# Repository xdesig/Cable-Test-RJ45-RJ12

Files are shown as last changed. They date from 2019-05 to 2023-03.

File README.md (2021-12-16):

# Cable Test V0.4

You want a PCB to exercise or learn to solder THT components, here you have one of many.
This provides you with a device to test network cables (RJ45) and telephone cables (RJ12 / 11),
made with normal components, (the most complicated being the LED bar).
You can be complemented with more diodes 1N4148 in anti-parallel soldiers under the LEDS (2, 5..9) to allow to check all cable faults.

Buy PCB in [PCBWAY]

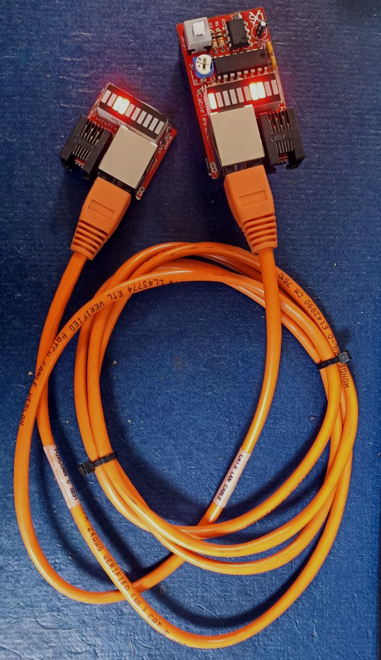
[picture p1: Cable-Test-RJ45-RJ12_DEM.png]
Top view

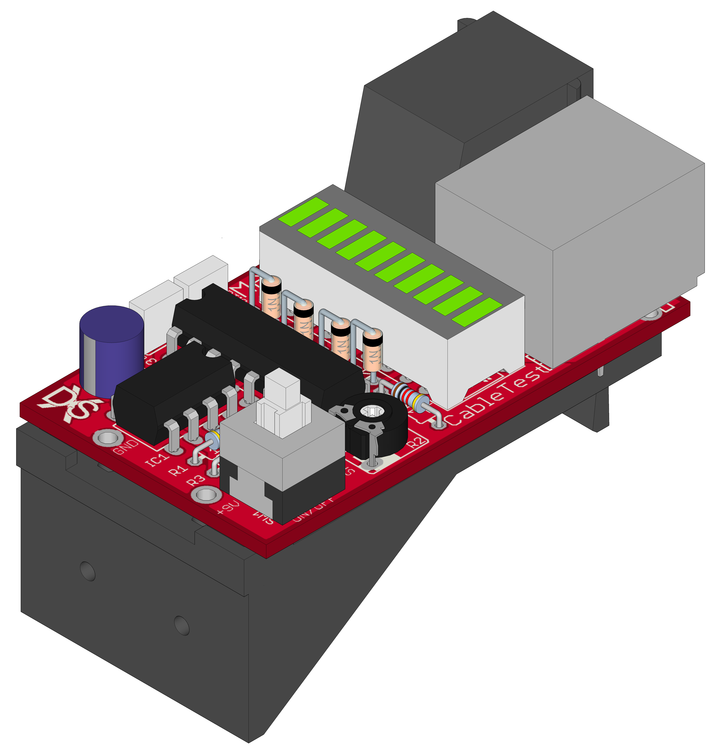
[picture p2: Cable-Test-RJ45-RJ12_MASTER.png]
Render

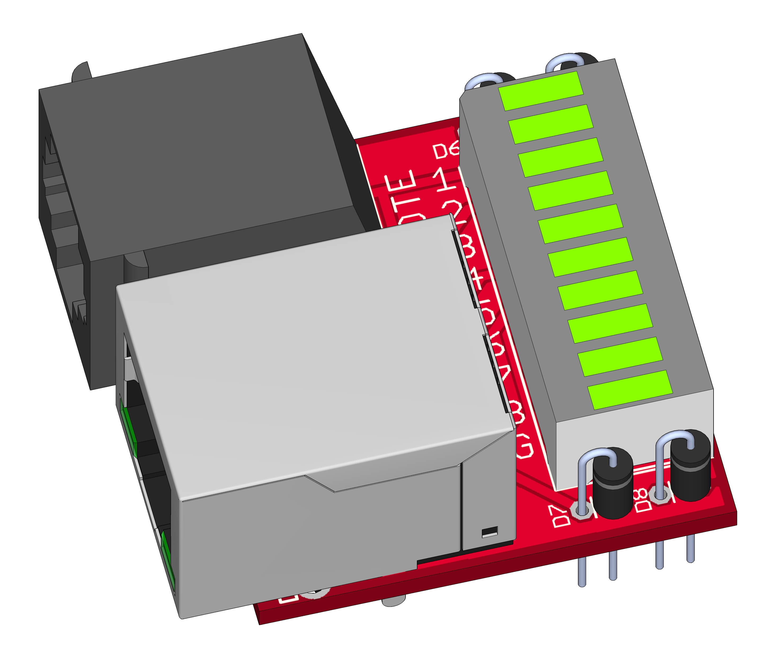
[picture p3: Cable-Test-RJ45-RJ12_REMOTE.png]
Botom view


#B.O.M.
<table cellspacing="0" border="0">
	<colgroup width="38"></colgroup>
	<colgroup width="70"></colgroup>
	<colgroup span="2" width="133"></colgroup>
	<colgroup width="122"></colgroup>
	<colgroup width="85"></colgroup>
	<tr>
		<td height="17" align="left">Qty </td>
		<td align="left">Value</td>
		<td align="left">Device</td>
		<td align="left">Package</td>
		<td align="left">Parts</td>
		<td align="left">Description</td>
	</tr>
	<tr>
		<td height="17" align="left"><br></td>
		<td align="left"><br></td>
		<td align="left"><br></td>
		<td align="left"><br></td>
		<td align="left"><br></td>
		<td align="left"><br></td>
	</tr>
	<tr>
		<td height="17" align="right" sdval="2" sdnum="1110;">2</td>
		<td align="left"><br></td>
		<td align="left"> DS1128-S80BP</td>
		<td align="left">DS1128-S80BP</td>
		<td align="left">J1, J3</td>
		<td align="left">Ethernet Connector</td>
	</tr>
	<tr>
		<td height="17" align="right" sdval="1" sdnum="1110;">1</td>
		<td align="left"><br></td>
		<td align="left"> BATTERY9V</td>
		<td align="left">BATTCON_9V</td>
		<td align="left">BAT1</td>
		<td align="left">Battery Holders</td>
	</tr>
	<tr>
		<td height="17" align="right" sdval="1" sdnum="1110;">2</td>
		<td align="left">100nF</td>
		<td align="left"> C2.5/2</td>
		<td align="left">C2.5-2</td>
		<td align="left">C2, C3</td>
		<td align="left">CAPACITOR</td>
	</tr>
	<tr>
		<td height="17" align="right" sdval="2" sdnum="1110;">2</td>
		<td align="left">10K</td>
		<td align="left"> 1/4 Watt</td>
		<td align="left">0204/7</td>
		<td align="left">R1, R3</td>
		<td align="left">RESISTOR</td>
	</tr>
	<tr>
		<td height="17" align="right" sdval="1" sdnum="1110;">1</td>
		<td align="left">10uF/16V</td>
		<td align="left">2.5mm&ndash;6mm</td>
		<td align="left">E2,5-6</td>
		<td align="left">C1</td>
		<td align="left">POLARIZED CAPACITOR</td>
	</tr>
	<tr>
		<td height="17" align="right" sdval="1" sdnum="1110;">1</td>
		<td align="left">1K</td>
		<td align="left"> R-EU_0204/7</td>
		<td align="left">0204/7</td>
		<td align="left">R4</td>
		<td align="left">RESISTOR</td>
	</tr>
	<tr>
		<td height="17" align="right" sdval="1" sdnum="1110;">8</td>
		<td align="left">1N4148</td>
		<td align="left"> DIODE-D-2.5</td>
		<td align="left">D-2.5</td>
		<td align="left">D1...D8</td>
		<td align="left">DIODE</td>
	</tr>
	<tr>
		<td height="17" align="right" sdval="1" sdnum="1110;">1</td>
		<td align="left">4017N</td>
		<td align="left"> 4017N</td>
		<td align="left">DIL16</td>
		<td align="left">IC2</td>
		<td align="left">COUNTER/DIVIDER</td>
	</tr>
	<tr>
		<td height="17" align="right" sdval="1" sdnum="1110;">1</td>
		<td align="left">47K</td>
		<td align="left"> TRIM_EU-CA6V</td>
		<td align="left">CA6V</td>
		<td align="left">R2</td>
		<td align="left">POTENTIOMETER</td>
	</tr>
	<tr>
		<td height="17" align="right" sdval="1" sdnum="1110;">1</td>
		<td align="left">NE555</td>
		<td align="left"> ICM555</td>
		<td align="left">DIL08</td>
		<td align="left">IC1</td>
		<td align="left">TIMER</td>
	</tr>
	<tr>
		<td height="17" align="right" sdval="1" sdnum="1110;">2</td>
		<td align="left">LB10</td>
		<td align="left"> LB10</td>
		<td align="left">LB10</td>
		<td align="left">LB1,LB2</td>
		<td align="left">10 LED BLOCK</td>
	</tr>
	<tr>
		<td height="17" align="right" sdval="1" sdnum="1110;">1</td>
		<td align="left">SW</td>
		<td align="left"> PB7-0</td>
		<td align="left">PB07_0</td>
		<td align="left">SW1</td>
		<td align="left">8x8mm   DPDT Self-locking Switch</td>
	</tr>
	<tr>
		<td height="17" align="right" sdval="2" sdnum="1110;">2</td>
		<td align="left">RJ11</td>
		<td align="left"> RJ11-6PTH</td>
		<td align="left">95001-6P6C</td>
		<td align="left">J2, J4</td>
		<td align="left">RJ12 Socket 95001-6P6C Female</td>
	</tr>
</table>

## Author and license
* Author: [XDeSIG][TWI01]
* License: CERN-OHL-W V2 [CERN-OHL] and Attribution-ShareAlike 4.0 International [CCBY-SA4.0]

<!-- links -->

[CERN-OHL]: https://ohwr.org/cernohl
[CCBY-SA4.0]: http://creativecommons.org/licenses/by-sa/4.0/
[TWI01]: https://twitter.com/xdesig
[DEM]: Cable-Test-RJ45-RJ12_DEM.png
[PHT]: Cable-Test-RJ45-RJ12_MASTER.png
[RENDER]: Cable-Test-RJ45-RJ12_REMOTE.png

[PCBWAY]: https://www.pcbway.com/project/shareproject/Cable_Test_RJ45___RJ12.html

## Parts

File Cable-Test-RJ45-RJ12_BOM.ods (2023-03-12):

Qty | Value | Device | Package | Parts | Description | LCSC link (https://www.lcsc.com/)
2 |  | DS1128-S80BP | DS1128-S80BP | J1, J3 | Ethernet Connector | C86586 (https://www.lcsc.com/product-detail/Ethernet-Connectors-Modular-Connectors-RJ45-RJ11_CONNFLY-Elec-DS1128-S80BP_C86586.html)
1 |  | BATTERY9V | BATTCON_9V | BAT1 | Battery Holders |  | Aliexpress (https://es.aliexpress.com/item/32945156022.html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)
2 | 100nF | C2.5/2 | C2.5-2 | C2,C3 | CAPACITOR | C353904 (https://www.lcsc.com/product-detail/Ceramic-Disc-Capacitors_Dersonic-CC1H104ZC1PD3F5P3003_C353904.html)
2 | 10K | 1/4 Watt | 0204/7 | R1, R3 | RESISTOR | C61299 (https://www.lcsc.com/product-detail/Through-Hole-Resistors_UNI-ROYAL-Uniroyal-Elec-CFR0W4J0103A50_C61299.html)
1 | 10uF/16V | 2.5mm – 6mm | E2,5-6 | C1 | POLARIZED CAPACITOR | C1664919 (https://www.lcsc.com/product-detail/Aluminum-Electrolytic-Capacitors-Leaded_Rubycon-16TWL10KEFC6-3X11_C1664919.html)
1 | 1K | R-EU_0204/7 | 0204/7 | R4 | RESISTOR | C176465 (https://www.lcsc.com/product-detail/Through-Hole-Resistors_YAGEO-MFR-25JT-52-1K_C176465.html)
8 | 1N4148 | DIODE-D-2.5 | D-2.5 | D1 ... D8 | DIODE | C14538 (https://www.lcsc.com/product-detail/Switching-Diode_ST-Semtech-1N4148_C14538.html)
1 | HC4017N | HC4017N | DIL16 | IC2 | COUNTER/DIVIDER | C1548031 (https://www.lcsc.com/product-detail/Counters-Dividers_Texas-Instruments-CD74HC4017EG4_C1548031.html)
1 | 47K | TRIM_EU-CA6V | CA6V | R2 | POTENTIOMETER | C840703 (https://www.lcsc.com/product-detail/Variable-Resistors-Potentiometers_BOURNS-3306F-1-103_C840703.html)
1 | NE555 | ICM555 | DIL08 | IC1 | TIMER | C5157852 (https://www.lcsc.com/product-detail/Timers-Clock-Oscillators_Gcore-NE555_C5157852.html)
2 | LB10 | LB10 | LB10 | LB1, LB2 | 10 LED BLOCK |  | Aliexpress (https://es.aliexpress.com/item/32346585157.html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)
1 | SW | PB7-0 | PB07_0 | SW1 | 8x8mm DPDT Self-locking Switch | C194403 (https://www.lcsc.com/product-detail/Push-span-style-background-color-ff0-Switches-span_GANGYUAN-PB21E09471-32_C194403.html)
2 | RJ12 | RJ12-6PTH | 95001-6P6C | J2, J4 | RJ12 Socket 95001-6P6C Female | C2902699 (https://www.lcsc.com/product-detail/Ethernet-Connectors-Modular-Connectors-RJ45-span-style-background-color-ff0-RJ11-span_Ckmtw-Shenzhen-Cankemeng-R-RJ11R06P-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)

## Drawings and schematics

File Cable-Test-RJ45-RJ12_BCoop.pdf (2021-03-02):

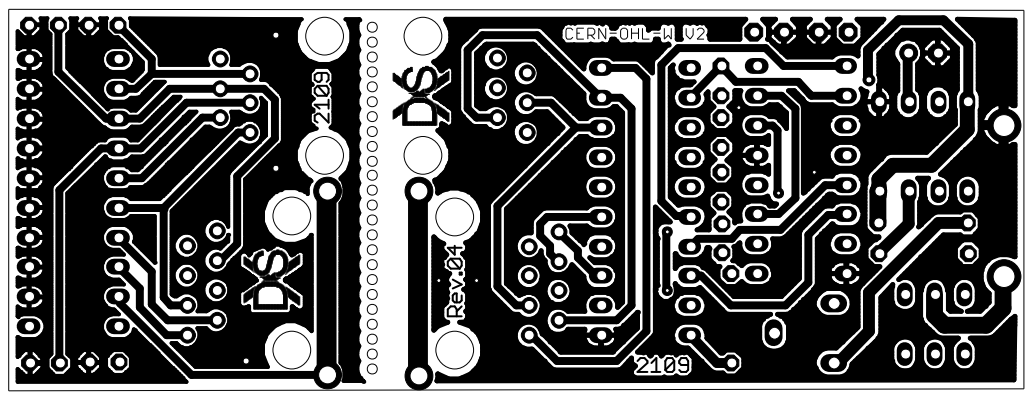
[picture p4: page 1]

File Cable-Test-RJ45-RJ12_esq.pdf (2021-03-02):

1 J1 2345678

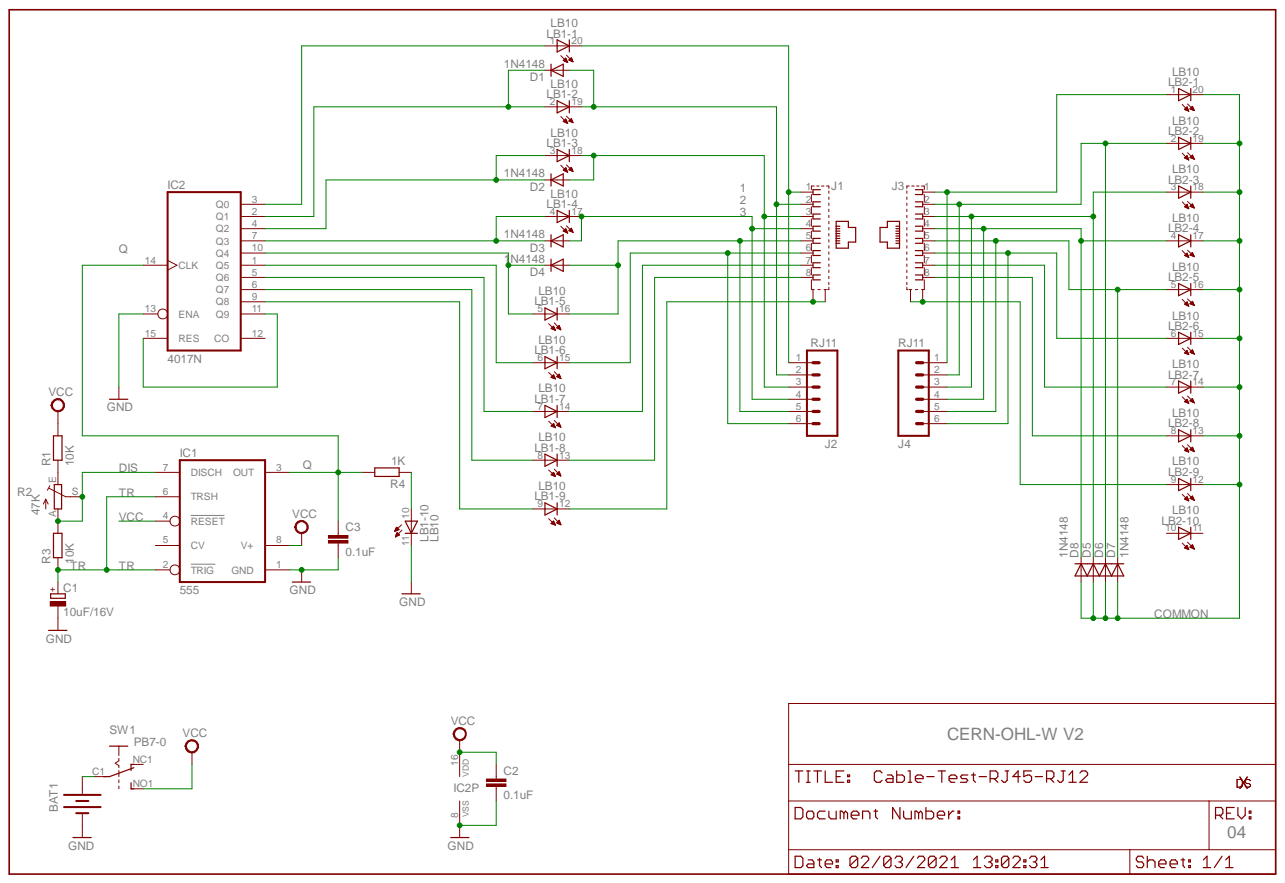
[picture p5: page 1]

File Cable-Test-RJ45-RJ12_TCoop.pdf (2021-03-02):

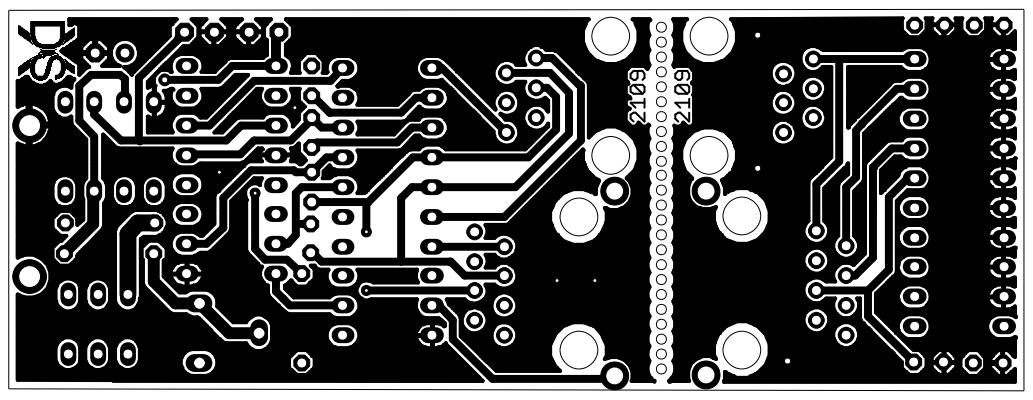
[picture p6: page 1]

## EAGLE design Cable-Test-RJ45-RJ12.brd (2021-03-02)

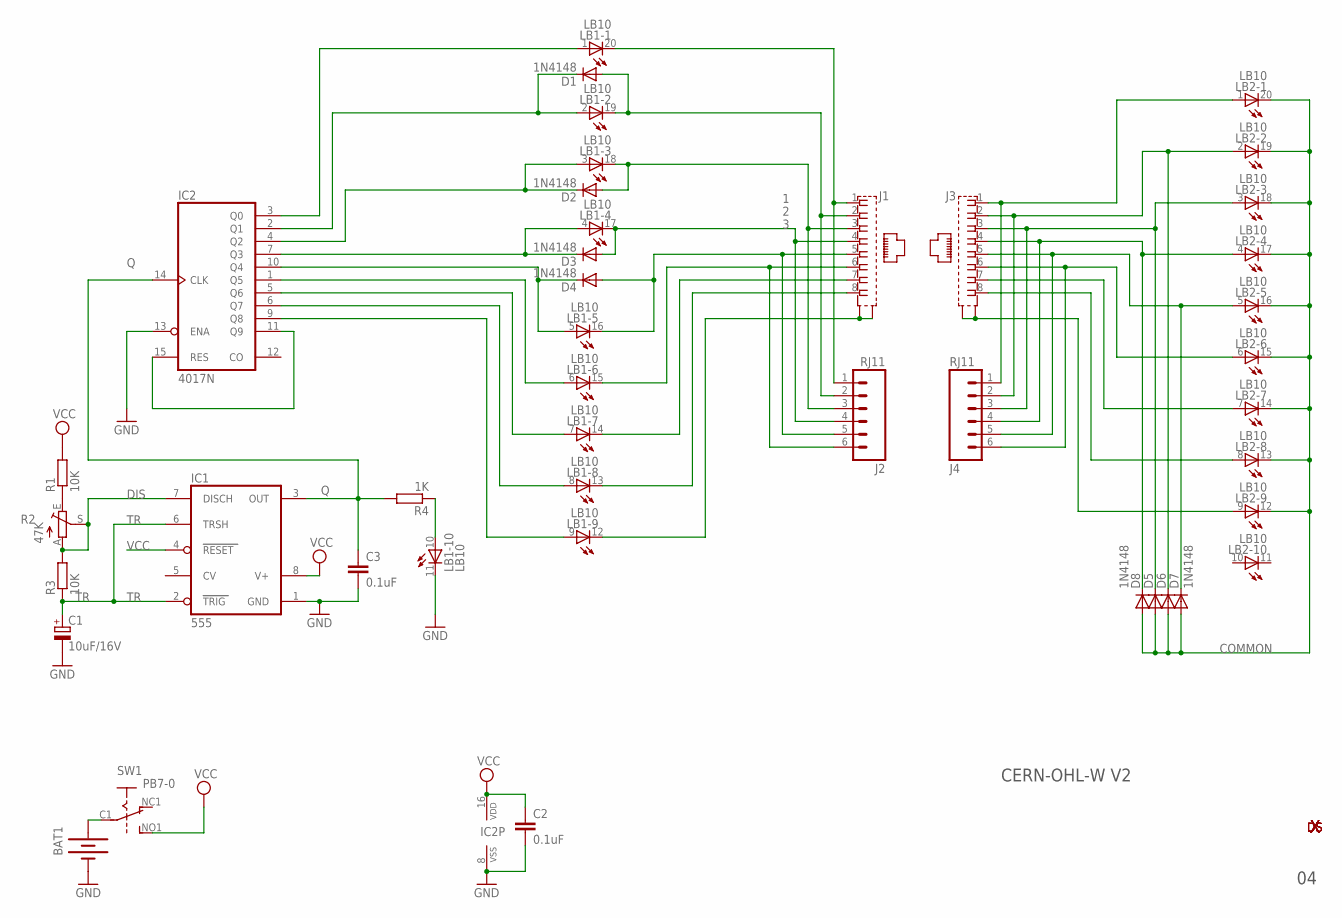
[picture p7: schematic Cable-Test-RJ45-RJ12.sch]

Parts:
$1_23_$: XDESIG21; XDESIG
BAT1: BATTERY9V; BATTCON_9V
C1: 10uF/16V; E2,5-6
C2, C3: 0.1uF; C2.5-2
D1, D2, D3, D4, D6, D7: 1N4148; D-2.5
D5, D8: DIODE-D-2.5; D-2.5
IC1: 555; DIL08
IC2: 4017N; DIL16
J1, J3: 555153-1
J2, J4: RJ11; RJ11-6
LB1, LB2: LB10
R1, R3: 10K; 0204/7
R2: 47K; CA6V
R4: 1K; 0204/7
SW1: PB7-0; PB07_0
U$6: XDESIG5MM; XDESIG_CU

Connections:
1: J1.1, J2.1, LB1.20 (C)
2: D1.A, J1.2, J2.2, LB1.19 (C)
3: D2.A, J1.3, J2.3, LB1.18 (C)
4: D3.A, J1.4, J2.4, LB1.17 (C)
COMMON: D5.A, D6.A, D7.A, D8.A, LB2.12 (C), LB2.13 (C), LB2.14 (C), LB2.15 (C), LB2.16 (C), LB2.17 (C), LB2.18 (C), LB2.19 (C), LB2.20 (C)
DIS: IC1.7 (DISCH), R2.A, R2.S, R3.2
G: J1.G1 (S1), J1.G2 (S2), LB1.12 (C)
GND: BAT1.-, C1.-, C2.2, C3.2, IC1.1 (GND), IC2.8 (VSS), IC2.13 (ENA), LB1.11 (C)
unnamed: IC2.11 (Q9), IC2.15 (RES)
unnamed: D6.C, J3.2, J4.2, LB2.2 (A)
unnamed: D2.C, IC2.4 (Q2), LB1.3 (A)
unnamed: D5.C, J3.3, J4.3, LB2.3 (A)
unnamed: IC2.3 (Q0), LB1.1 (A)
unnamed: D8.C, J3.4, J4.4, LB2.4 (A)
unnamed: D7.C, J3.5, J4.5, LB2.5 (A)
unnamed: D4.A, J1.5, J2.5, LB1.16 (C)
unnamed: IC2.9 (Q8), LB1.9 (A)
unnamed: J1.6, J2.6, LB1.15 (C)
unnamed: J3.6, J4.6, LB2.6 (A)
unnamed: D1.C, IC2.2 (Q1), LB1.2 (A)
unnamed: J3.7, LB2.7 (A)
unnamed: J3.8, LB2.8 (A)
unnamed: J3.G1 (S1), J3.G2 (S2), LB2.9 (A)
unnamed: D3.C, IC2.7 (Q3), LB1.4 (A)
unnamed: J3.1, J4.1, LB2.1 (A)
unnamed: R1.1, R2.E
unnamed: BAT1.+, SW1.C1
unnamed: D4.C, IC2.10 (Q4), LB1.5 (A)
unnamed: J1.7, LB1.14 (C)
unnamed: J1.8, LB1.13 (C)
unnamed: IC2.1 (Q5), LB1.6 (A)
unnamed: IC2.5 (Q6), LB1.7 (A)
unnamed: IC2.6 (Q7), LB1.8 (A)
unnamed: LB1.10 (A), R4.1
Q: C3.1, IC1.3 (OUT), IC2.14 (CLK), R4.2
TR: C1.+, IC1.2 (TRIG), IC1.6 (TRSH), R3.1
VCC: C2.1, IC1.4 (RESET), IC1.8 (V+), IC2.16 (VDD), R1.2, SW1.NO1 (S)

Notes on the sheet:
CERN-OHL-W V2

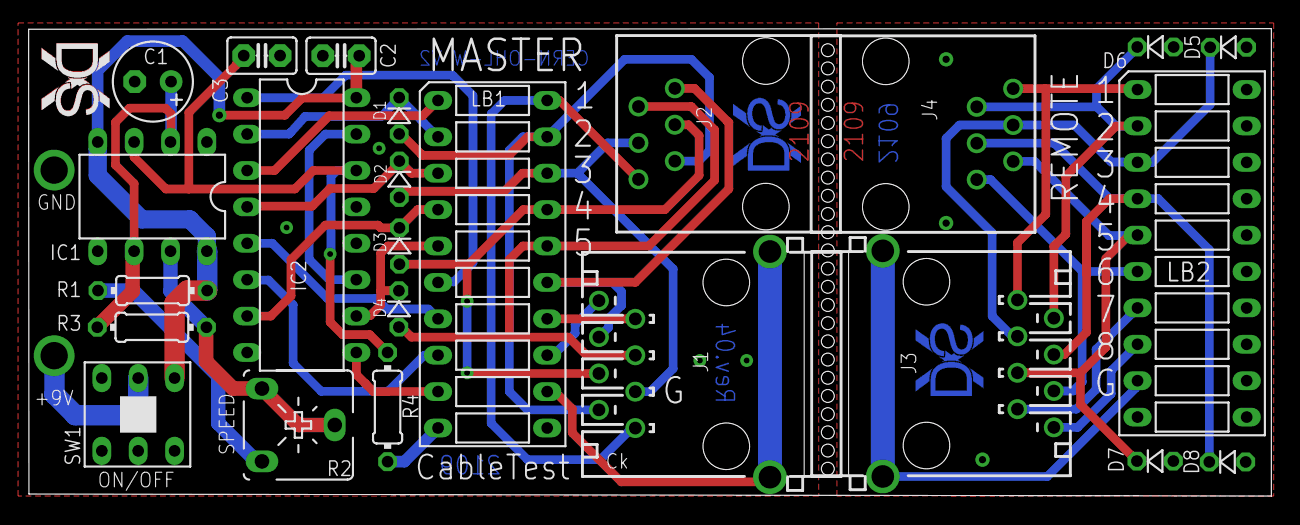
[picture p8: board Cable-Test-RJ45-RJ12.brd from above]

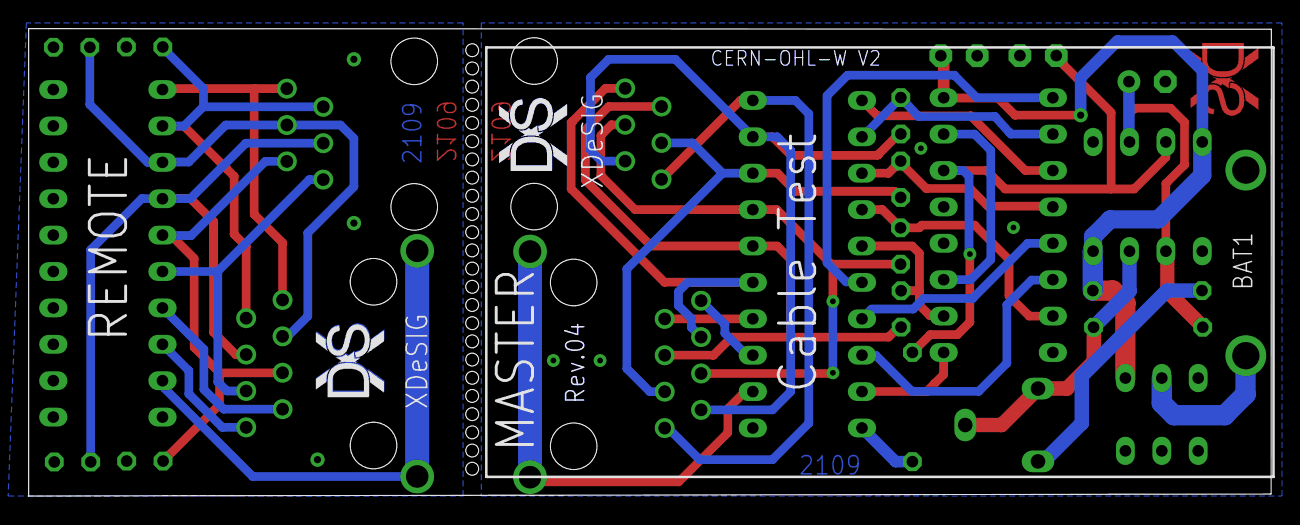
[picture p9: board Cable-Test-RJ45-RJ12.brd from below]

Board: 2 copper layers, 86.7 x 32.6 mm, 31 parts (5 on the bottom side), 37 nets.

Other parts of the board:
U$1, U$2: XDESIG5MM; XDESIG_CU
U$3, U$5: XDESIG21; XDESIG

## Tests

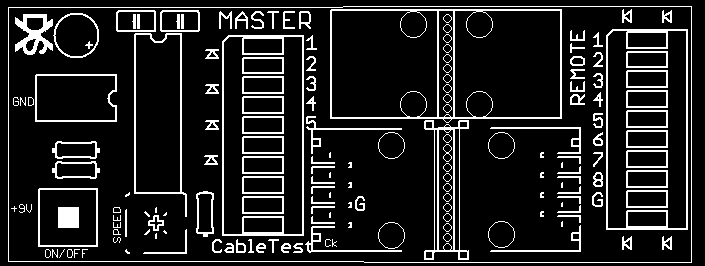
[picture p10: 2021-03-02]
Cable-Test-RJ45-RJ12_STop.png

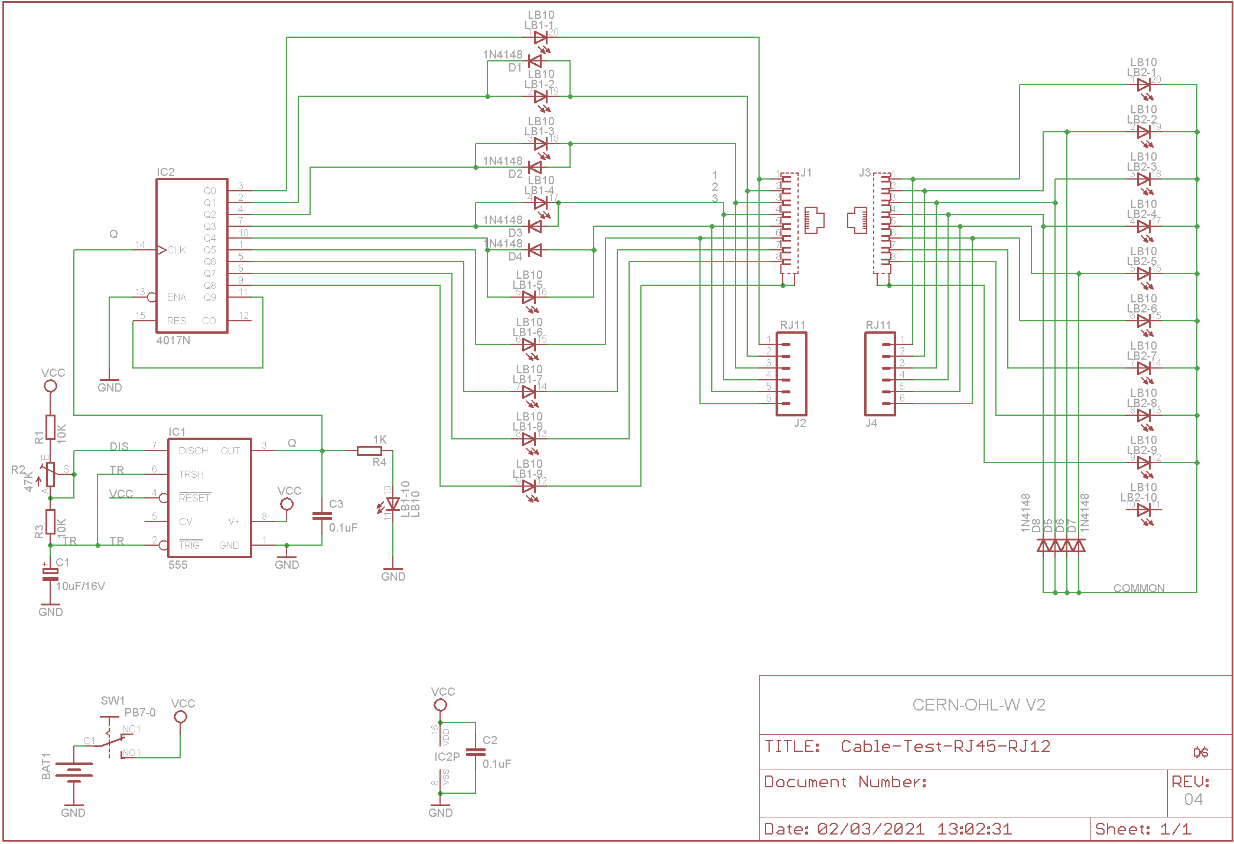
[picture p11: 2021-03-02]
Cable-Test-RJ45-RJ12_ESQ.png

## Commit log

2021-03-02 Version 0.4
    Version 0.4, I add a "C3" to stabilize the clock signal impulses
    [Cable-Test-RJ45-RJ12.brd, Cable-Test-RJ45-RJ12.sch, Cable-Test-RJ45-RJ12_BOM.ods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]
2021-03-02 Version 0.4
    [Cable-Test-RJ45-RJ12.brd, Cable-Test-RJ45-RJ12.sch, Cable-Test-RJ45-RJ12_BOM.ods]

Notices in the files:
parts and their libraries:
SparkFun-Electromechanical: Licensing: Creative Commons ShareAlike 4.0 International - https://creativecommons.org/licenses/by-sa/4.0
